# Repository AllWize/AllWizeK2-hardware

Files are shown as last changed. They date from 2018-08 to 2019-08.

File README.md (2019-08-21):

# AllWize K2

The AllWize K2 is an Arduino(TM) MKR compatible board based on the SAMD21G microchip and a RadioCrafts RC1701HP module.

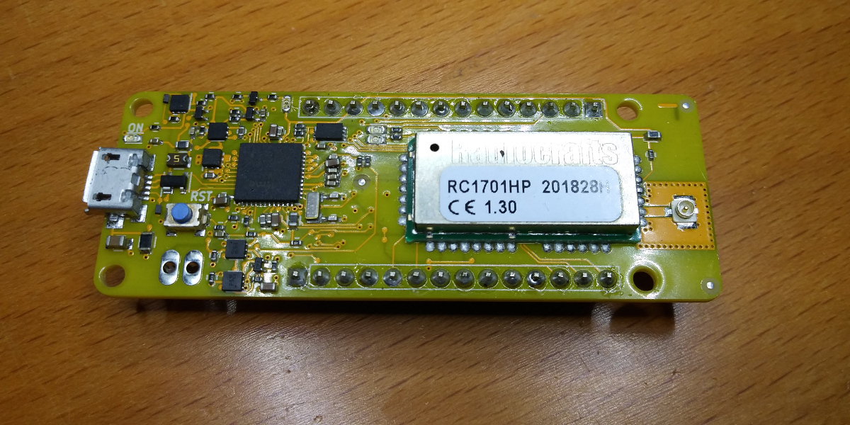
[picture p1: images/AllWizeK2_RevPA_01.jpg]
AllWize K2 RevPA


Resources:

* [AllWize K2 Wiki Page](http://wiki.allwize.io/index.php?title=Allwize_K2)
* [AllWize Boards](https://github.com/AllWize/allwize-boards) to support the AllWize K2 board from the Arduino IDE and PlatformIO
* [AllWize Library](https://github.com/AllWize/allwize) that supports the RC1701HP radio module.

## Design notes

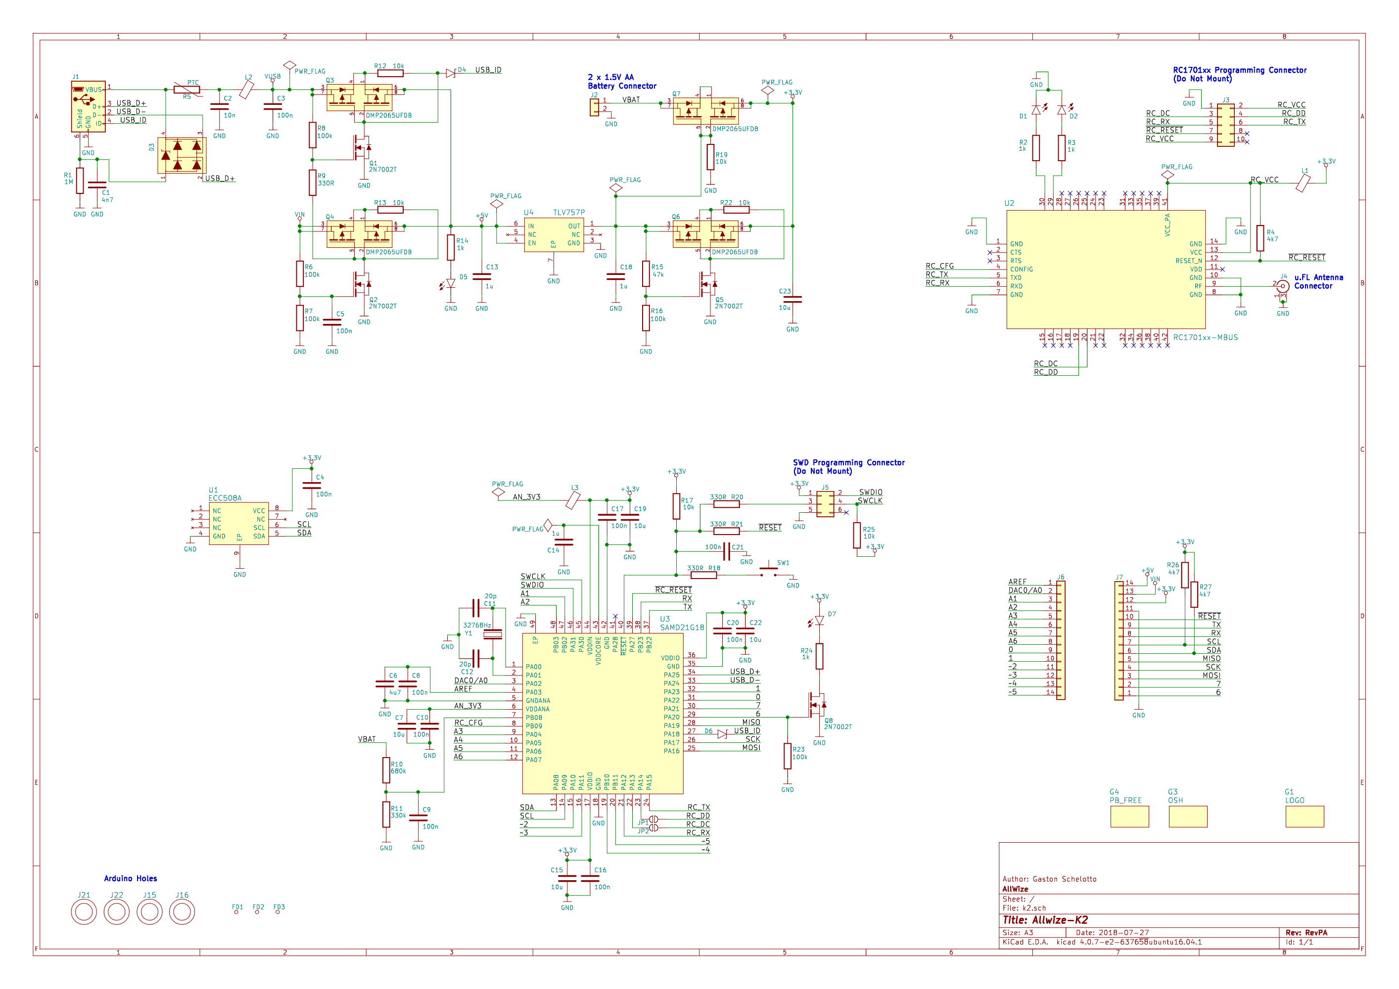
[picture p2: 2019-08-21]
images/AllWizeK2_RevPA_schematic.png

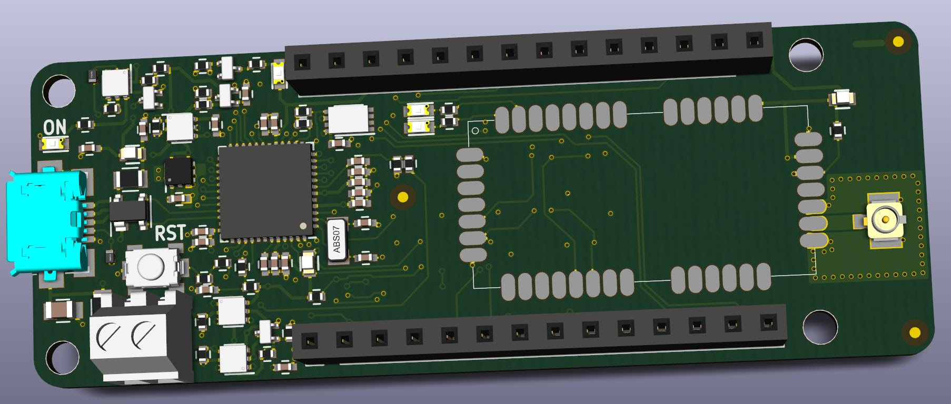
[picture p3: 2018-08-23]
RevPA/pcb/K2_RevPA_front.jpg

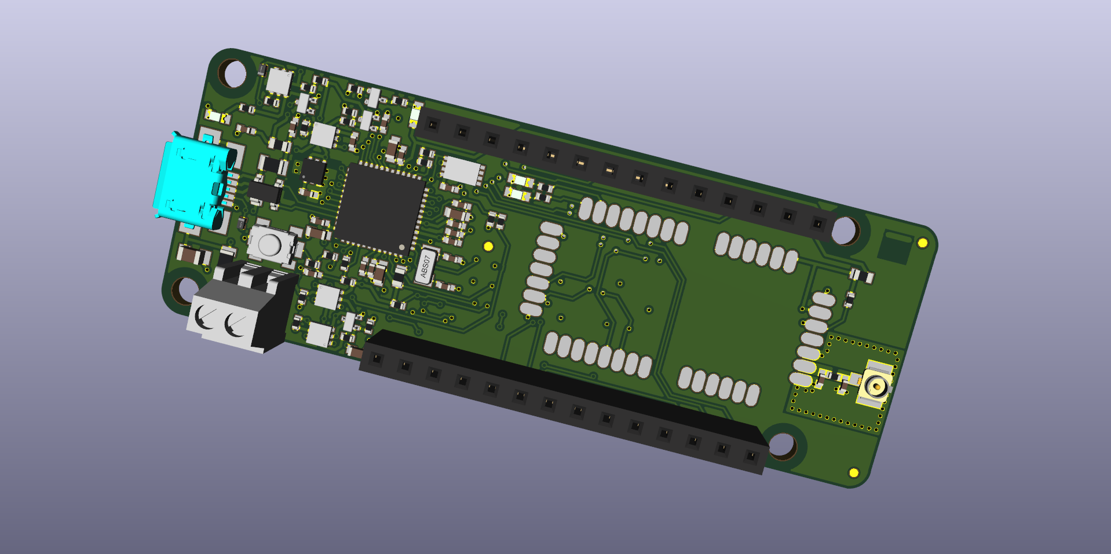
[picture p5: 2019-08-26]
RevPB/bhikeeoiimaponhm.png

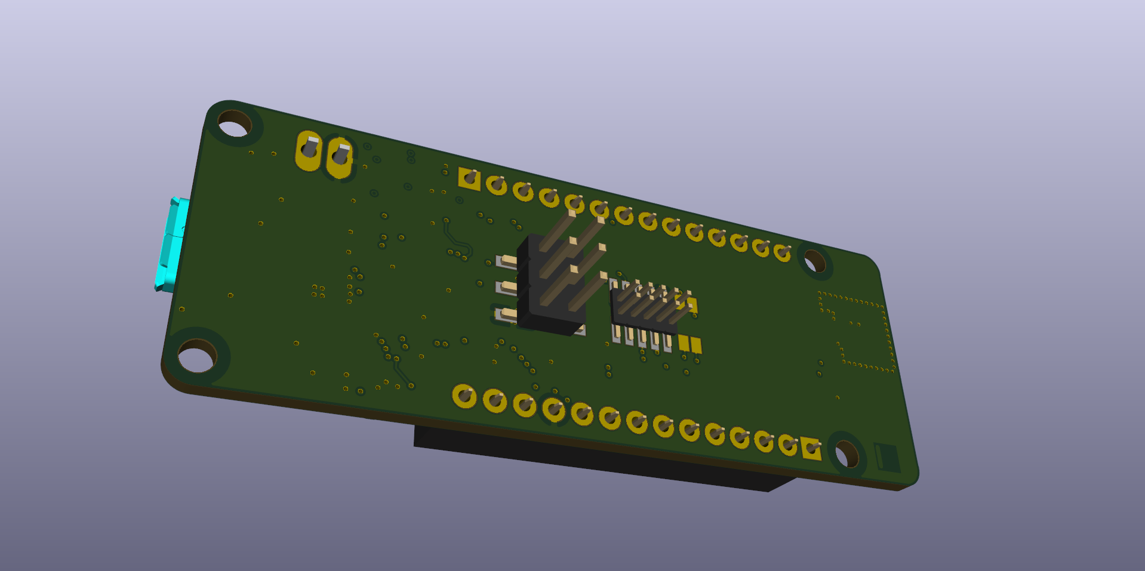
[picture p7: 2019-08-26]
RevPB/omigknjlmflmiijo.png

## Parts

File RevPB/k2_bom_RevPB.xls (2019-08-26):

Component | Part | References | Value | Quantity Per PCB | Function | Mounting Option | PN | Alternative PN
1 | C | C4 C8 C10 C16 C17 C20 | 100n | 6 | Coupling Capacitor |  | GCM155R71H104KE02D
2 | C | C3 C5 C9 C21 | 100n | 4 | Filter Capacitor |  | GCM155R71H104KE02D
3 | C | C2 | 10n | 1 | Filter Capacitor |  | GRM155R71H103KA88J
4 | C | C7 C15 C19 C22 C23 | 10u | 5 | Coupling Capacitor |  | GRM188R61C106KAALD
5 | C | C13 C14 C18 | 1u | 3 | Coupling Capacitor |  | GRM155R61E105KA12D
6 | C | C11 C12 | 20p | 2 | Xtal Capacitor |  | CBR04C200J5GAC
7 | C | C1 | 4n7 | 1 | Shielding Capacitor |  | C0805V472KDRACTU
8 | C | C6 | 4u7 | 1 | Coupling Capacitor |  | GRM155R60J475ME47D
9 | C | C24 | 12p | 1 | Filter Capacitor | NP | GRM1555C1H120JA01J
10 | C | C25 | 12p | 1 | Filter Capacitor |  | GRM1555C1H120JA01J
11 | LED-DIODE | D1 D2 D5 | LED-DIODE | 3 | Green LED |  | KPHD-1608LVZGCK
12 | LED-DIODE | D7 | LED-DIODE | 1 | Yellow LED |  | KPHD-1608LVSYCK
13 | PMEG2005EL | D4 D6 | PMEG2005EL | 2 | Schottky Diode |  | PMEG2005EL,315
14 | PRTR5V0U2X | D3 | PRTR5V0U2X | 1 | ESD protection diode |  | PRTR5V0U2X,215
15 | LOGO | G2 | LABEL | 1 | Label Zone |  | NA
16 | LOGO | G1 | LOGO | 1 | Logo Mark |  | NA
17 | LOGO | G3 | OSH | 1 | Logo Mark |  | NA
18 | LOGO | G4 | PB_FREE | 1 | Logo Mark |  | NA
19 | Conn_01x02 | J2 | Conn_01x02 | 1 | 1x2 Terminal screw connector |  | OSTVN02A150
20 | Conn_01x14 | J6 J7 | Conn_01x14 | 2 | Headers Strip 14 ways Arduino MKR1000 Printed |  | C000118 | PPTC141LFBN-RC
21 | Conn_02x03_Odd_Even | J5 | Conn_02x03_Odd_Even | 1 | ICSP 2x3 Connector | NP | M20-8760342
22 | Conn_02x05_Odd_Even | J3 | Conn_02x05_Odd_Even | 1 | 2x5 Connector | NP | 20021121-00010C4LF
23 | Conn_Coaxial_uFL | J4 | Conn_Coaxial_uFL | 1 | uFL Antenna Connector |  | U.FL-R-SMT(10)
24 | NPTH-HOLE | J15 J16 J21 J22 | NPTH-HOLE | 4 | NPTH Hole |  | NA
25 | USB_B_Micro | J1 | USB_B_Micro | 1 | Micro B-USB connector |  | ZX62-AB-5PA(31)
26 | SolderJumper_2_Open | JP1 JP2 | SolderJumper_2_Open | 2 | Open Jumper |  | NA
27 | Ferrite_Bead | L1 L2 L3 | Ferrite_Bead | 3 | Ferrite Bead |  | BLM18SG331TN1
28 | NMOS | Q1 Q2 Q5 Q8 | 2N7002T | 4 | N-Channel MOSFET |  | 2N7002T-7-F
29 | DMP2065UFDB | Q3 Q4 Q6 Q7 | DMP2065UFDB | 4 | Dual P-Channel Enhancement Mode MOSFET |  | DMP2065UFDB-7
30 | R | R6 R7 R8 R13 R16 R19 R22 | 100k | 7 | Voltage divider resistor |  | CRCW0402100KFKEDC
31 | R | R23 | 100k | 1 | Pull-down resistor |  | CRCW0402100KFKEDC
32 | R | R12 | 10k | 1 | Gate resistor |  | CRCW040210K0FKEDC
33 | R | R17 R25 | 10k | 2 | Pull-up resistor |  | CRCW040210K0FKEDC
34 | R | R1 | 1M | 1 | Shielding resistor |  | RCV08051M00FKEA
35 | R | R2 R3 R14 R24 | 1k | 4 | Series Resistor |  | RCS04021K00FKED
36 | R | R18 R20 R21 | 330R | 3 | Series resistor |  | RC0402FR-07330RL
37 | R | R9 | 330R | 1 | Voltage divider resistor |  | RC0402FR-07330RL
38 | R | R11 | 330k | 1 | Voltage divider resistor |  | CRCW0402330KFKEDC
39 | R | R15 | 47k | 1 | Voltage divider resistor |  | RC0402FR-0747KL
40 | R | R4 R26 R27 | 4k7 | 3 | Pull-up resistor |  | RC0402FR-074K7L
41 | R | R10 | 680k | 1 | Voltage divider resistor |  | RC0402FR-07680KL
42 | L | L4 | 20n | 1 | Fixed Inductor |  | LQW15AN20NG00D
43 | PTC | R5 | PTC | 1 | PTC Fuse |  | MF-PSMF075X-2
44 | PUSHBUTTON | SW1 | PUSHBUTTON | 1 | Push Button |  | PTS820 J25K SMTR LFS
45 | ECC508A | U1 | ECC508A | 1 | Crypto Authentication Device |  | ATECC508A-MAHDA-T
46 | RC1701xx-MBUS | U2 | RC1701xx-MBUS | 1 | M-Bus High power RF Transceiver Module |  | RC1701HP-MBUS4
47 | SAMD21G18 | U3 | SAMD21G18 | 1 | Low-Power 32-bit Cortex-M0+ MCU |  | ATSAMD21G18A-MU
48 | TLV757P | U4 | TLV757P | 1 | LDO Voltage Regulator |  | TLV75733PDRVR
49 | 32768Hz | Y1 | 32768Hz | 1 | 32768Hz Crystal Oscillator |  | ABS07-32.768KHZ-T

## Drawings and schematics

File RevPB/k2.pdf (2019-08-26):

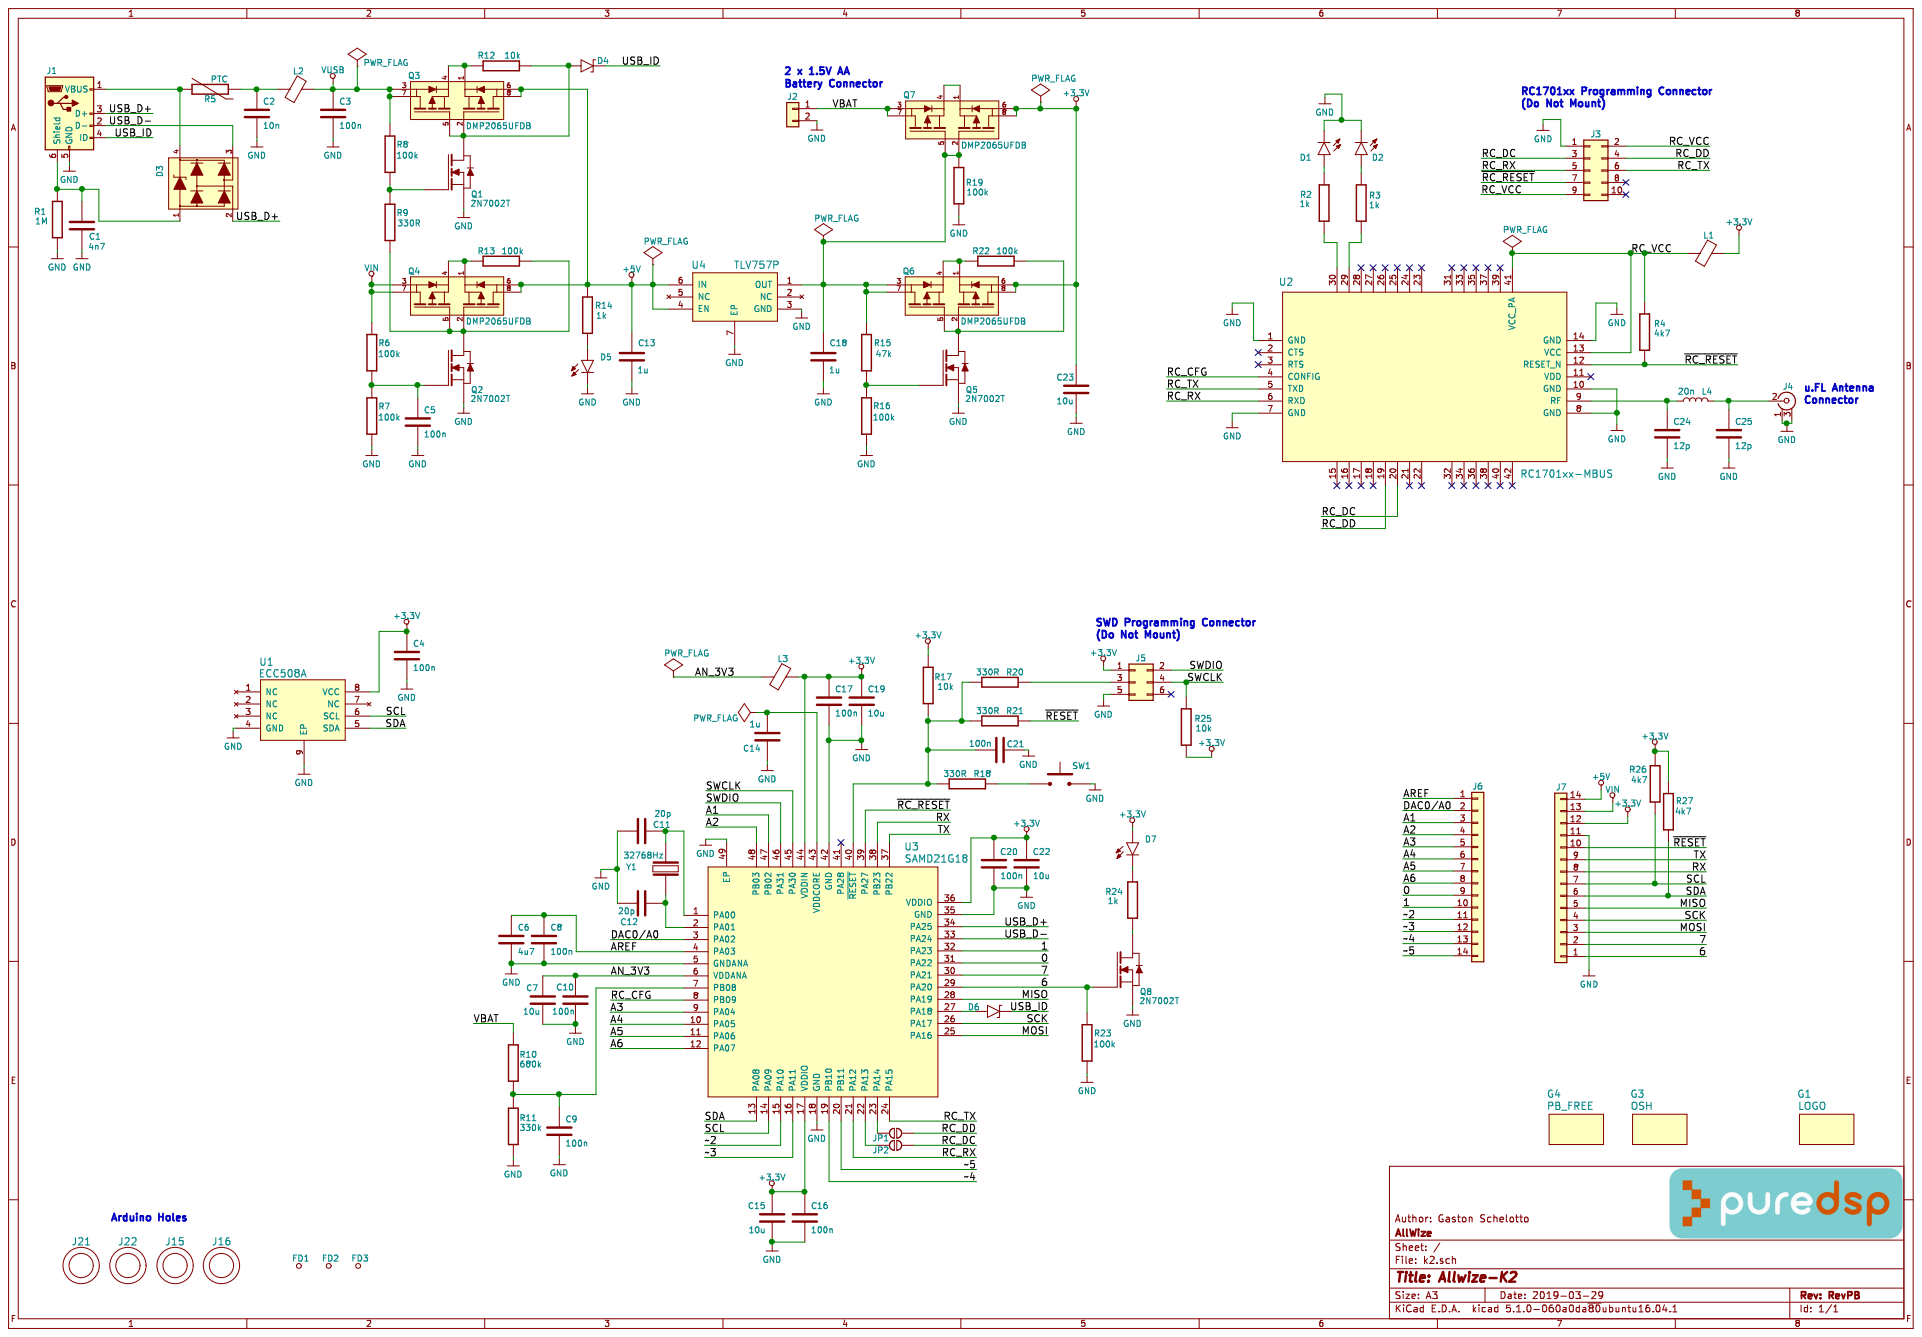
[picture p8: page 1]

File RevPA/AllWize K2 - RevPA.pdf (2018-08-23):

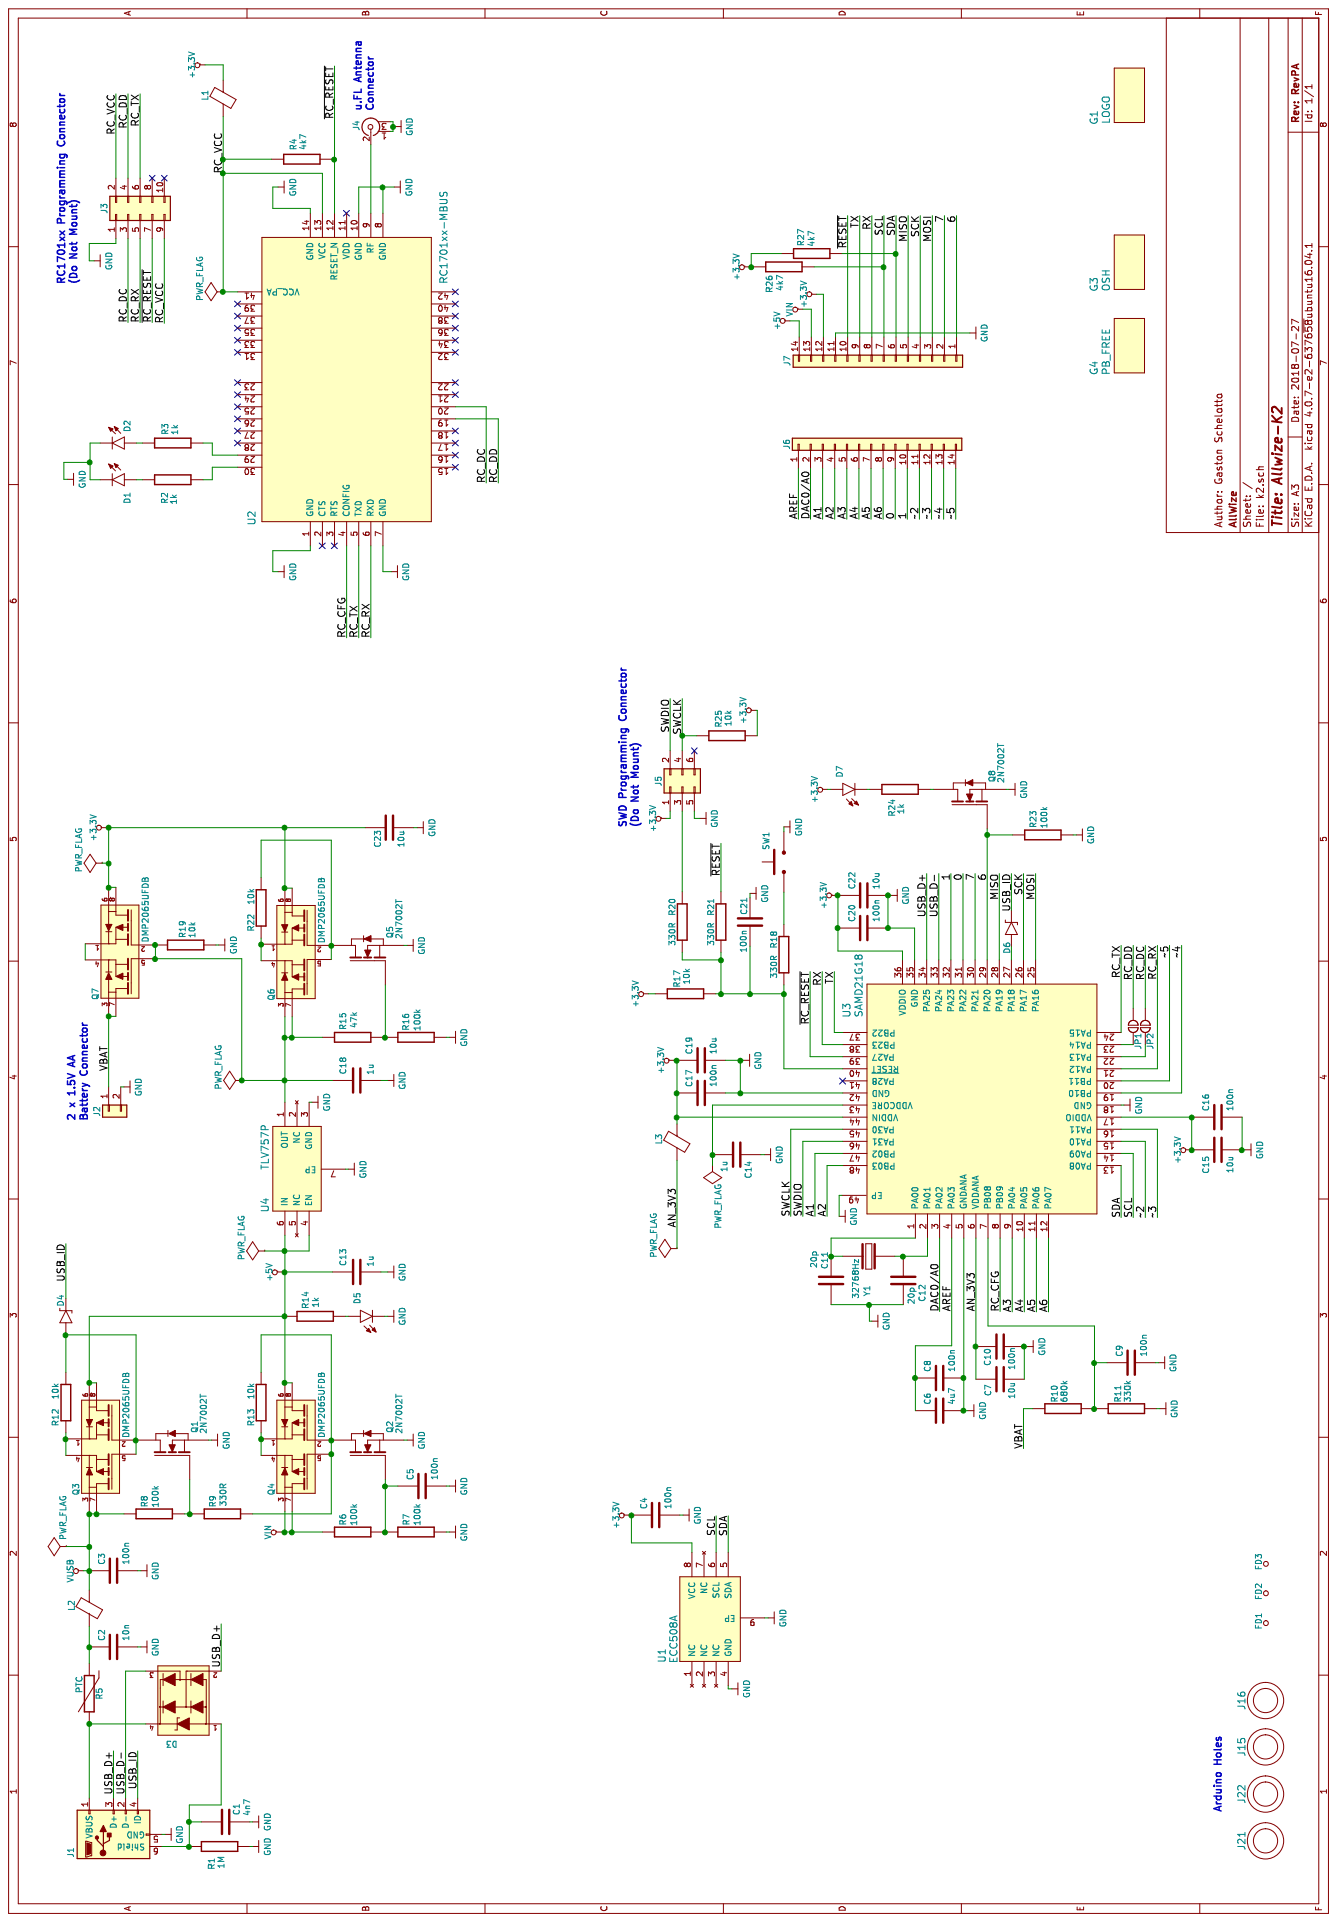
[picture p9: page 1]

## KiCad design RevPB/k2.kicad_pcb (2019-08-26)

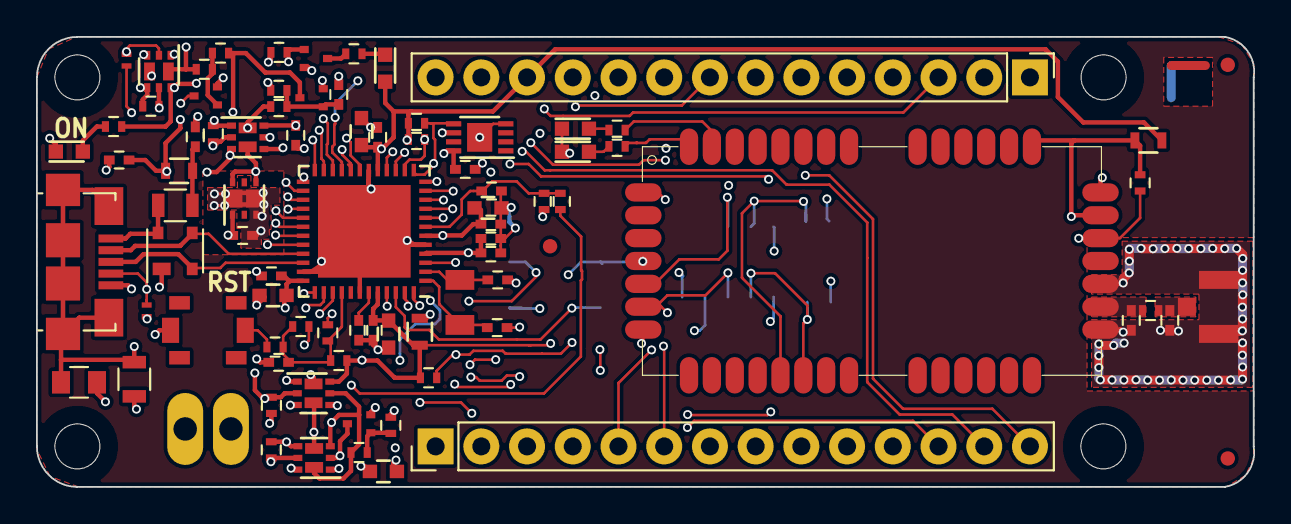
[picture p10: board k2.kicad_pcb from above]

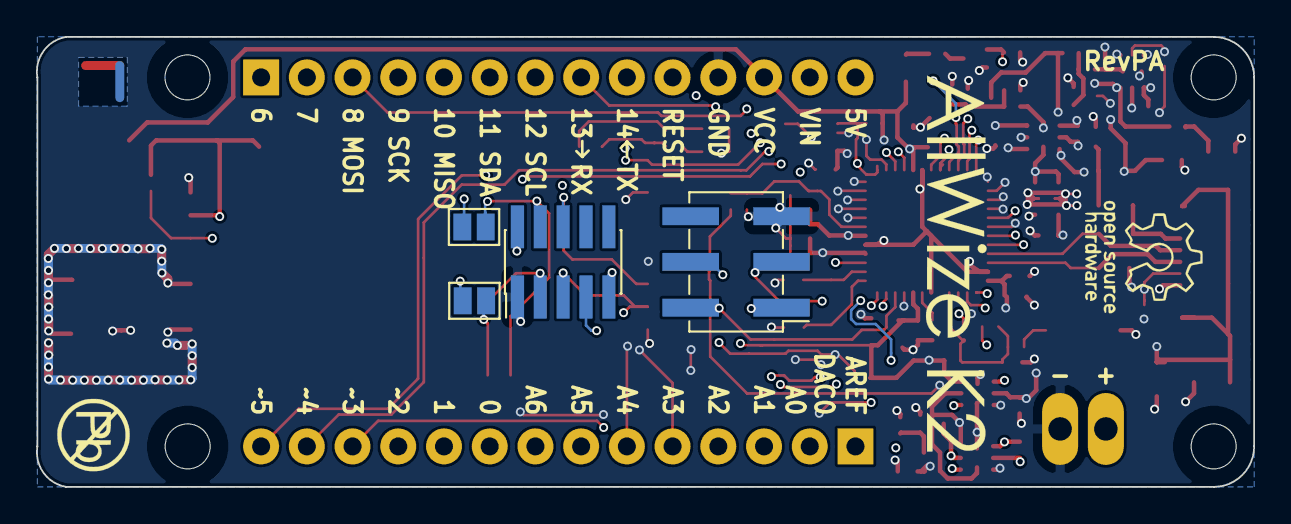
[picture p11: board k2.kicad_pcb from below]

Board: 4 copper layers, 67.6 x 25.0 mm, 96 parts (7 on the bottom side), 75 nets.

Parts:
C1: 4n7; C_0805
C2: 10n; C_0402
C3, C4, C5, C8, C9, C10, C16, C17, C20, C21: 100n; C_0402
C6: 4u7; C_0402
C7, C15, C19, C22, C23: 10u; C_0603
C11, C12: 20p; C_0402
C13, C14, C18: 1u; C_0402
C24, C25: 12p; C_0402
D1, D2, D5, D7: LED-DIODE; LED_0603
D3: PRTR5V0U2X; SOT-143
D4, D6: PMEG2005EL; SOD-882
FD1, FD2, FD3: FIDUCIAL; FIDUCIAL-08
G1: LOGO; allwize-k2-logo
G3: OSH; osh
G4: PB_FREE; Pb-free
J1: USB_B_Micro; USB_Micro-B_ZX62-AB-5PA_31
J2: Conn_01x02; OSTVN02
J3: Conn_02x05_Odd_Even; PinHeader_2x05_P1.27mm_Vertical_SMD
J4: Conn_Coaxial_uFL; uFL-CONN
J5: Conn_02x03_Odd_Even; PinHeader_2x03_P2.54mm_Vertical_SMD
J6, J7: Conn_01x14; PinHeader_1x14_P2.54mm_Vertical
J15, J16, J21, J22: NPTH-HOLE; HOLE_2.5MM
JP1, JP2: SolderJumper_2_Open; SolderJumper-2_P1.3mm_Open_Pad1.0x1.5mm
L1, L2, L3: Ferrite_Bead; R_0603
L4: 20n; R_0402
Q1, Q2, Q5, Q8: 2N7002T; SOT-523-3
Q3, Q4, Q6, Q7: DMP2065UFDB; U-DFN2020-6
R1: 1M; R_0805
R2, R3, R14, R24: 1k; R_0402
R4, R26, R27: 4k7; R_0402
R5: PTC; R_0805
R6, R7, R8, R16, R23: 100k; R_0402
R9, R18, R20, R21: 330R; R_0402
R10: 680k; R_0402
R11: 330k; R_0402
R12, R13, R17, R19, R22, R25: 10k; R_0402
R15: 47k; R_0402
SW1: PUSHBUTTON; PTS8020
U1: ECC508A; UDFN-8-1EP_3x2mm_P0.5mm_EP1.4x1.6mm
U2: RC1701xx-MBUS
U3: SAMD21G18; QFN-48-1EP_7x7mm_P0.5mm_EP5.15x5.15mm
U4: TLV757P; WSON-6
Y1: 32768Hz; ABS07-32768Hz

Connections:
+3.3V: C4.1, C15.1, C16.1, C17.1, C19.1, C20.1, C22.1, C23.1, D7.2, J5.1, J7.12, L1.1, L3.1, Q6.6, Q6.8, Q7.6, Q7.8, R17.2, R25.1, R26.2, R27.2, U1.8, U3.17, U3.36, U3.44
+5V: C13.1, J7.14, Q3.6, Q3.8, Q4.6, Q4.8, R14.2, U4.4, U4.6
/0: J6.9, U3.31
/1: J6.10, U3.32
/6: J7.1, Q8.1, R23.2, U3.29
/7: J7.2, U3.30
/A1: J6.3, U3.47
/A2: J6.4, U3.48
/A3: J6.5, U3.9
/A4: J6.6, U3.10
/A5: J6.7, U3.11
/A6: J6.8, U3.12
/AN_3V3: C7.1, C10.1, L3.2, U3.6
/AREF: C6.1, C8.1, J6.1, U3.4
/DAC0/A0: J6.2, U3.3
/MISO: J7.5, U3.28
/MOSI: J7.3, U3.25
/RC_CFG: U2.4, U3.8
/RC_DC: J3.3, JP2.2, U2.20
/RC_DD: J3.4, JP1.2, U2.19
/RC_RX: J3.5, U2.6, U3.21
/RC_TX: J3.6, U2.5, U3.24
/RC_VCC: J3.2, J3.9, L1.2, R4.2, U2.13, U2.41
/RX: J7.8, U3.38
/SCK: J7.4, U3.26
/SCL: J7.7, R26.1, U1.6, U3.14
/SDA: J7.6, R27.1, U1.5, U3.13
/SWCLK: J5.4, R25.2, U3.45
/SWDIO: J5.2, U3.46
/TX: J7.9, U3.37
/USB_D+: D3.2, J1.3, U3.34
/USB_D-: D3.3, J1.2, U3.33
/USB_ID: D4.2, D6.2, J1.4
/VBAT: J2.1, Q7.3, Q7.7, R10.2
/~RC_RESET~: J3.7, R4.1, U2.12, U3.39
/~RESET~: J7.10, R21.2
/~~2: J6.11, U3.15
/~~3: J6.12, U3.16
/~~4: J6.13, U3.19
/~~5: J6.14, U3.20
GND: C1.2, C2.2, C3.2, C4.2, C5.2, C6.2, C7.2, C8.2, C9.2, C10.2, C11.2, C12.2, C13.2, C14.1, C15.2, C16.2, C17.2, C18.2, C19.2, C20.2, C21.2, C22.2, C23.2, C24.2, C25.2, D1.1, D2.1, D5.1, J1.5, J2.2, J3.1, J4.1, J4.3, J5.5, J7.11, Q1.2, Q2.2, Q5.2, Q8.2, R1.1, R7.1, R11.1, R16.1, R19.1, R23.1, SW1.2, U1.4, U1.9, U2.1, U2.7, U2.8, U2.10, U2.14, U3.5, U3.18, U3.35, U3.42, U3.49, U4.3, U4.7
unnamed: C1.1, D3.1, J1.6, R1.2
unnamed: C2.1, L2.2, R5.1
unnamed: C5.1, Q2.1, R6.1, R7.2
unnamed: C9.1, R10.1, R11.2, U3.7
unnamed: C11.1, U3.1, Y1.1
unnamed: C12.1, U3.2, Y1.2
unnamed: C14.2, U3.43
unnamed: C18.1, Q6.3, Q6.7, Q7.2, Q7.5, R15.2, R19.2, U4.1
unnamed: C21.1, R17.1, R18.1, R20.1, R21.1, U3.40
unnamed: C24.1, L4.1, U2.9
unnamed: C25.1, J4.2, L4.2
unnamed: D1.2, R2.1
unnamed: D2.2, R3.1
unnamed: D3.4, J1.1, R5.2
unnamed: D4.1, Q1.3, Q3.2, Q3.5, R12.1
unnamed: D5.2, R14.1
unnamed: D6.1, U3.27
unnamed: D7.1, R24.1
unnamed: J5.3, R20.2
unnamed: JP1.1, U3.23
unnamed: JP2.1, U3.22
unnamed: Q1.1, R8.1, R9.2
unnamed: Q2.3, Q4.2, Q4.5, R9.1, R13.1
unnamed: Q3.1, Q3.4, R12.2
unnamed: Q4.1, Q4.4, R13.2
unnamed: Q5.1, R15.1, R16.2
unnamed: Q5.3, Q6.2, Q6.5, R22.1
unnamed: Q6.1, Q6.4, R22.2
unnamed: Q7.1, Q7.4
unnamed: Q8.3, R24.2
unnamed: R2.2, U2.30
unnamed: R3.2, U2.29
unnamed: R18.2, SW1.1
VIN: C3.1, J7.13, L2.1, Q3.3, Q3.7, Q4.3, Q4.7, R6.2, R8.2

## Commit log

2019-08-21 Fix link to allwize-boards repo
2019-08-26 Adding RevPB
    [k2-B_Fab.gbr, k2-B_Mask.gbs, k2-B_Paste.gbp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]
